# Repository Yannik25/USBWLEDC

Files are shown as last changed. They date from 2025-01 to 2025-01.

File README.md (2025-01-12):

# USBWLEDC
USB Sound Reactive WLED Controller



## Features

- USB-C for flashing and power (max. 3A)
- Small size (30mm x 35mm)
- Cheap components
- GSA4737 MEMS Microphone (similar to SPM1423)
- Solder Pads instead of Screw Terminal Blocks
- Files for panelized version (4x4)
- Files for 3D printed case
- Front side can be populated by JLCPCB

 

## Case



## Entering Flash Mode

To enter the Flash mode of the USBWLEDC, simply hold down the button as you connect the USB cable to a computer.

\* Update: With Rev. 1.2, CH340C has auto reset functionality, there should be no need to press the button during connection. 

## WLED Config

| Name | Value |
|---|---|
| LED Output 1: GPIO | 32 |
| LED Output 2: GPIO | 33 |
| Button 0: GPIO | 0 |
| Digitalmic: Type | Generic I2S PDM |
| Digitalmic: Pin I2S SD | GPIO 23 |
| Digitalmic: Pin I2S WS | GPIO 22 |

## BOM

|Designators |Footprint |Quantity|Value |LCSC Part #|
|---|---|---|---|---|
|C1*, C2, C4, C9, C10 |Capacitor_SMD:C_0402_1005Metric |5 |100nF |C1525  |
|C3, C5, C7 |Capacitor_SMD:C_0603_1608Metric |3 |10uF |C96446  |
|C6 |Capacitor_SMD:C_0402_1005Metric |1 |1uF |C52923  |
|C8 |Capacitor_SMD:CP_Elec_5x5.4 |1 |100uF |C7469983 |
|J10 |Connector_USB:USB_C_Receptacle_G-Switch_GT-USB-7010ASV |1 |USB-C Receptacle |C2988369|
|MK1* |Microphone:Microphone-6pin |1 |ICS-43434 MEMS Microphone|C5656610|
|R1* |Resistor_SMD:R_0402_1005Metric |1 |100k |C25741  |
|R2, R3, R6, R7 |Resistor_SMD:R_0402_1005Metric |4 |10k |C25531  |
|R4, R5 |Resistor_SMD:R_0603_1608Metric |2 |5.1k |C23186  |
|SW1 |Button_Switch_SMD:SW_Push_1P1T_XKB_TS-1187A |1 |Push Button Flash |C318884 |
|U2 |Package_TO_SOT_SMD:SOT-223-3_TabPin2 |1 |AMS1117-3.3 |C6186 |
|U3** |RF_Module:ESP32-WROOM-32E |1 |ESP32-WROOM-32E |C701341 |
|U4 		|Package_SO:VSSOP-8_2.3x2mm_P0.5mm			|1 		|SN74LVC2T45DCUR 		|C15741 |
|U5 		|Package_SO:SOIC-16_3.9x9.9mm_P1.27mm		|1 		|CH340C 				|C84681  |
|Q1, Q2 |Package_TO_SOT_SMD:SOT-23 |2 |L8050QLT1G |C49581 |
|D1 |Package_TO_SOT_SMD:SOT-143 |1 |SP0503BAHT |C2682275 |

\* You can build it without the microphone. Then you don't need R1, C1 and MK1.

\*\* The ESP32-WROOM Module can be purchased at a lower cost on AliExpress.

## Assembly

When ordering from JLCPCB, you have the option to get the front side of the board pre-populated - A service I strongly endorse. Subsequently, you'll only need to solder the ESP32-WROOM module onto the reverse side. With sufficient flux, this task can be accomplished with relative ease.

For those looking to populate the whole board, I suggest using a hot plate or a reflow oven for the front side.

    Be careful to keep Isopropyl Alcohol away from the hole of the microphone when cleaning the board!

## Disclaimer

The circuit board provided on this GitHub repository is offered "as is," without any warranties or guarantees of any kind. By accessing and utilizing this circuit board, you acknowledge and agree that you do so at your own risk.

The creator and contributor of this repository, shall not be held responsible or liable for any damages, losses, or injuries that may occur as a result of building and / or using this circuit board. This includes but is not limited to any direct, indirect, consequential, or incidental damages.

Electricity is dangerous. Only attempt this project if you know what you're doing.

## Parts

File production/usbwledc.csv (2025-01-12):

Comment | Designator | Footprint | LCSC
100nF | C1,C2,C4,C9,C10 | Capacitor_SMD:C_0402_1005Metric | C1525
10uF | C3,C5,C7 | Capacitor_SMD:C_0603_1608Metric | C96446
1uF | C6 | Capacitor_SMD:C_0402_1005Metric | C52923
100uF | C8 | Capacitor_SMD:CP_Elec_5x5.4 | C7469983
SP0503BAHT | D1 | Package_TO_SOT_SMD:SOT-143 | C2682275
5V PAD | J1,J4 | Library:SolderWirePad_1x01_SMD_3x6mm
USB_C_Receptacle_USB2.0 | J10 | Connector_USB:USB_C_Receptacle_G-Switch_GT-USB-7010ASV | C2988369
D1 PAD | J2 | Library:SolderWirePad_1x01_SMD_3x6mm
GND PAD | J3,J6 | Library:SolderWirePad_1x01_SMD_3x6mm
D2 PAD | J5 | Library:SolderWirePad_1x01_SMD_3x6mm
Accessories | J7 | Connector_PinHeader_2.54mm:PinHeader_1x06_P2.54mm_Vertical
Conn_01x03_Pin | J8,J9 | Connector_PinHeader_2.54mm:PinHeader_1x03_P2.54mm_Vertical
ICS-43434 | MK1 | microphone:Microphone-6pin | C5656610
L8050QLT1G | Q1,Q2 | Package_TO_SOT_SMD:SOT-23 | C49581
100k | R1 | Resistor_SMD:R_0402_1005Metric | C25741
10k | R2,R3,R6,R7 | Resistor_SMD:R_0402_1005Metric | C25531
5.1k | R4,R5 | Resistor_SMD:R_0603_1608Metric | C23186
FLASH_SW | SW1 | Button_Switch_SMD:SW_Push_1P1T_XKB_TS-1187A | C318884
AMS1117-3.3 | U2 | Package_TO_SOT_SMD:SOT-223-3_TabPin2 | C6186
ESP32-WROOM-32E-N4 | U3 | RF_Module:ESP32-WROOM-32E | C701341
SN74LVC2T45DCUR | U4 | Package_SO:VSSOP-8_2.3x2mm_P0.5mm | C15741
CH340C | U5 | Package_SO:SOIC-16_3.9x9.9mm_P1.27mm | C84681

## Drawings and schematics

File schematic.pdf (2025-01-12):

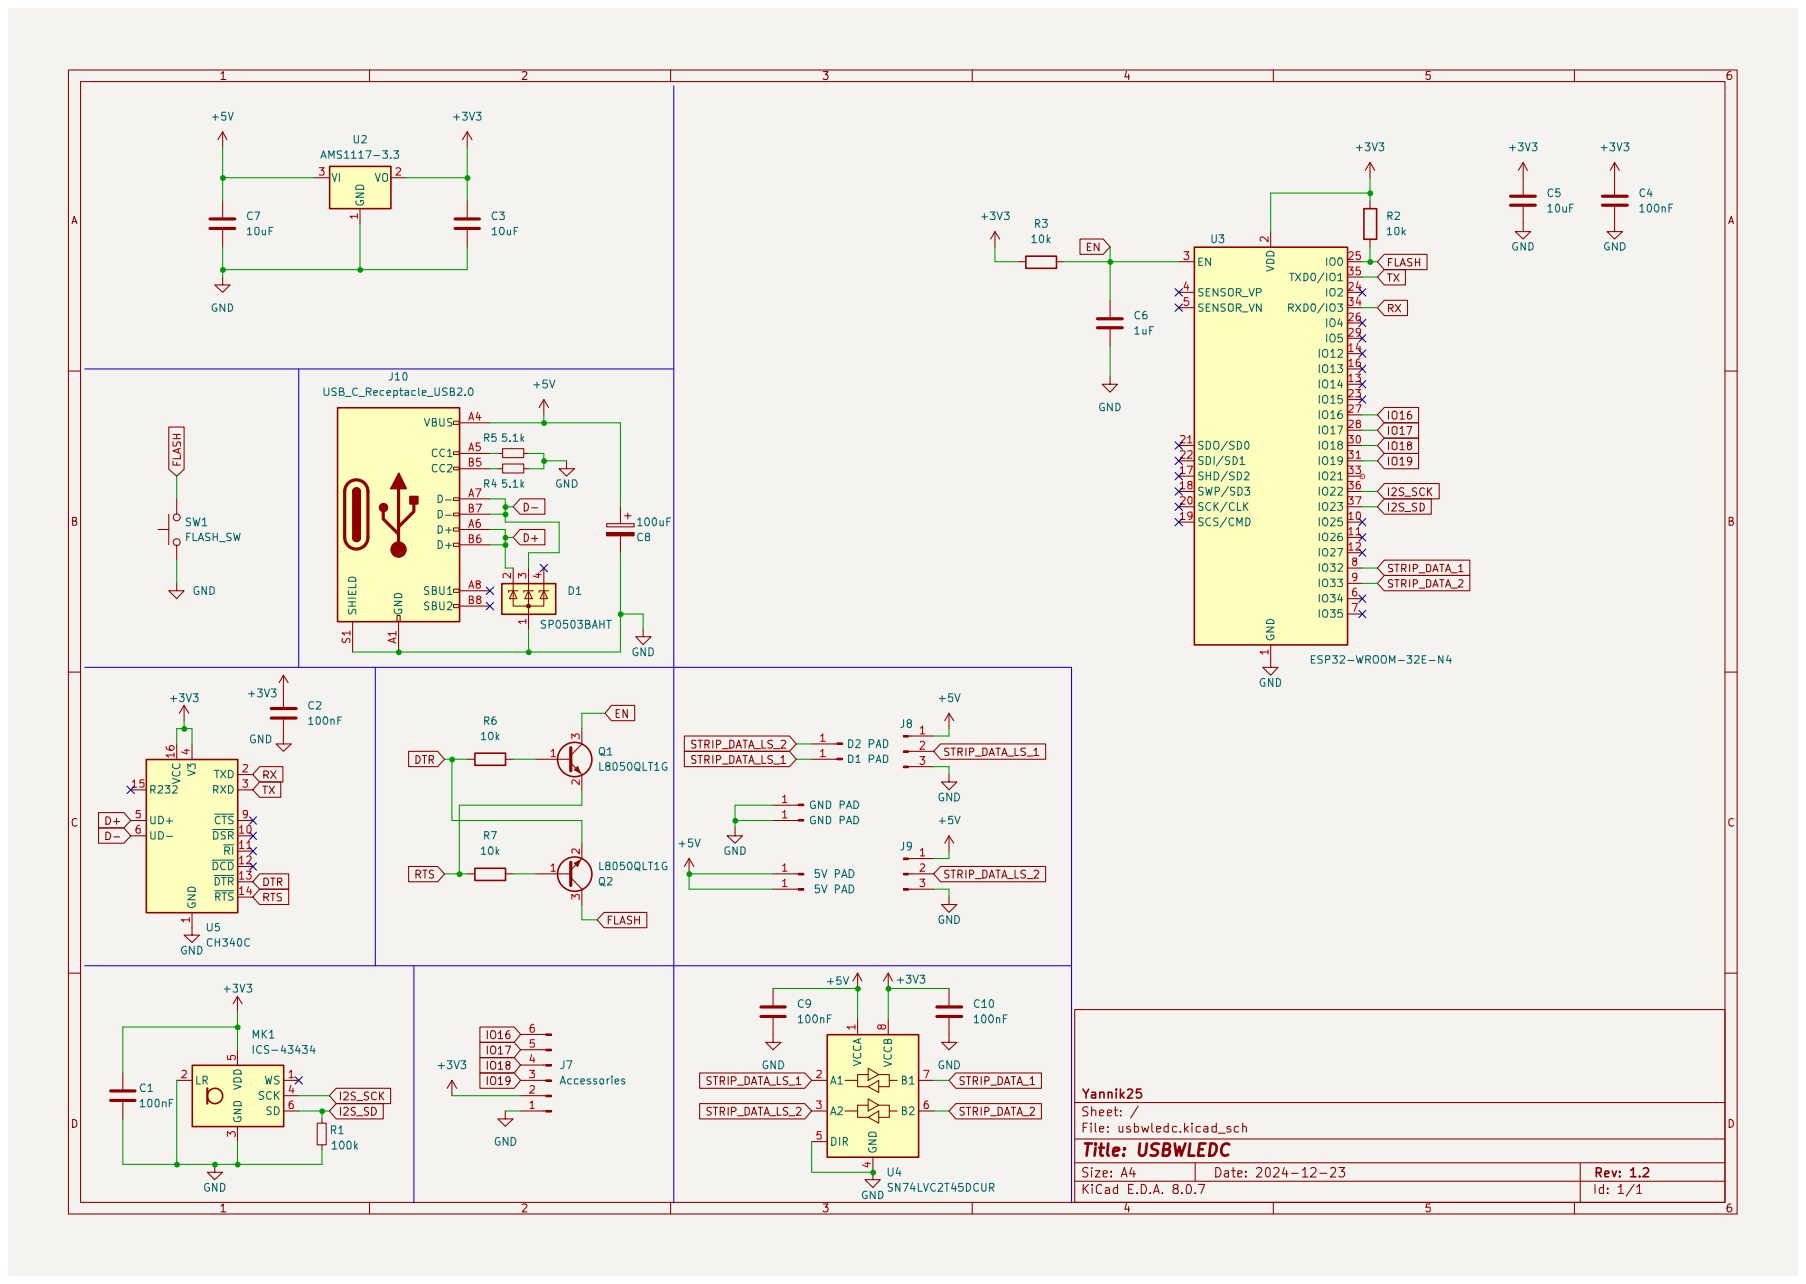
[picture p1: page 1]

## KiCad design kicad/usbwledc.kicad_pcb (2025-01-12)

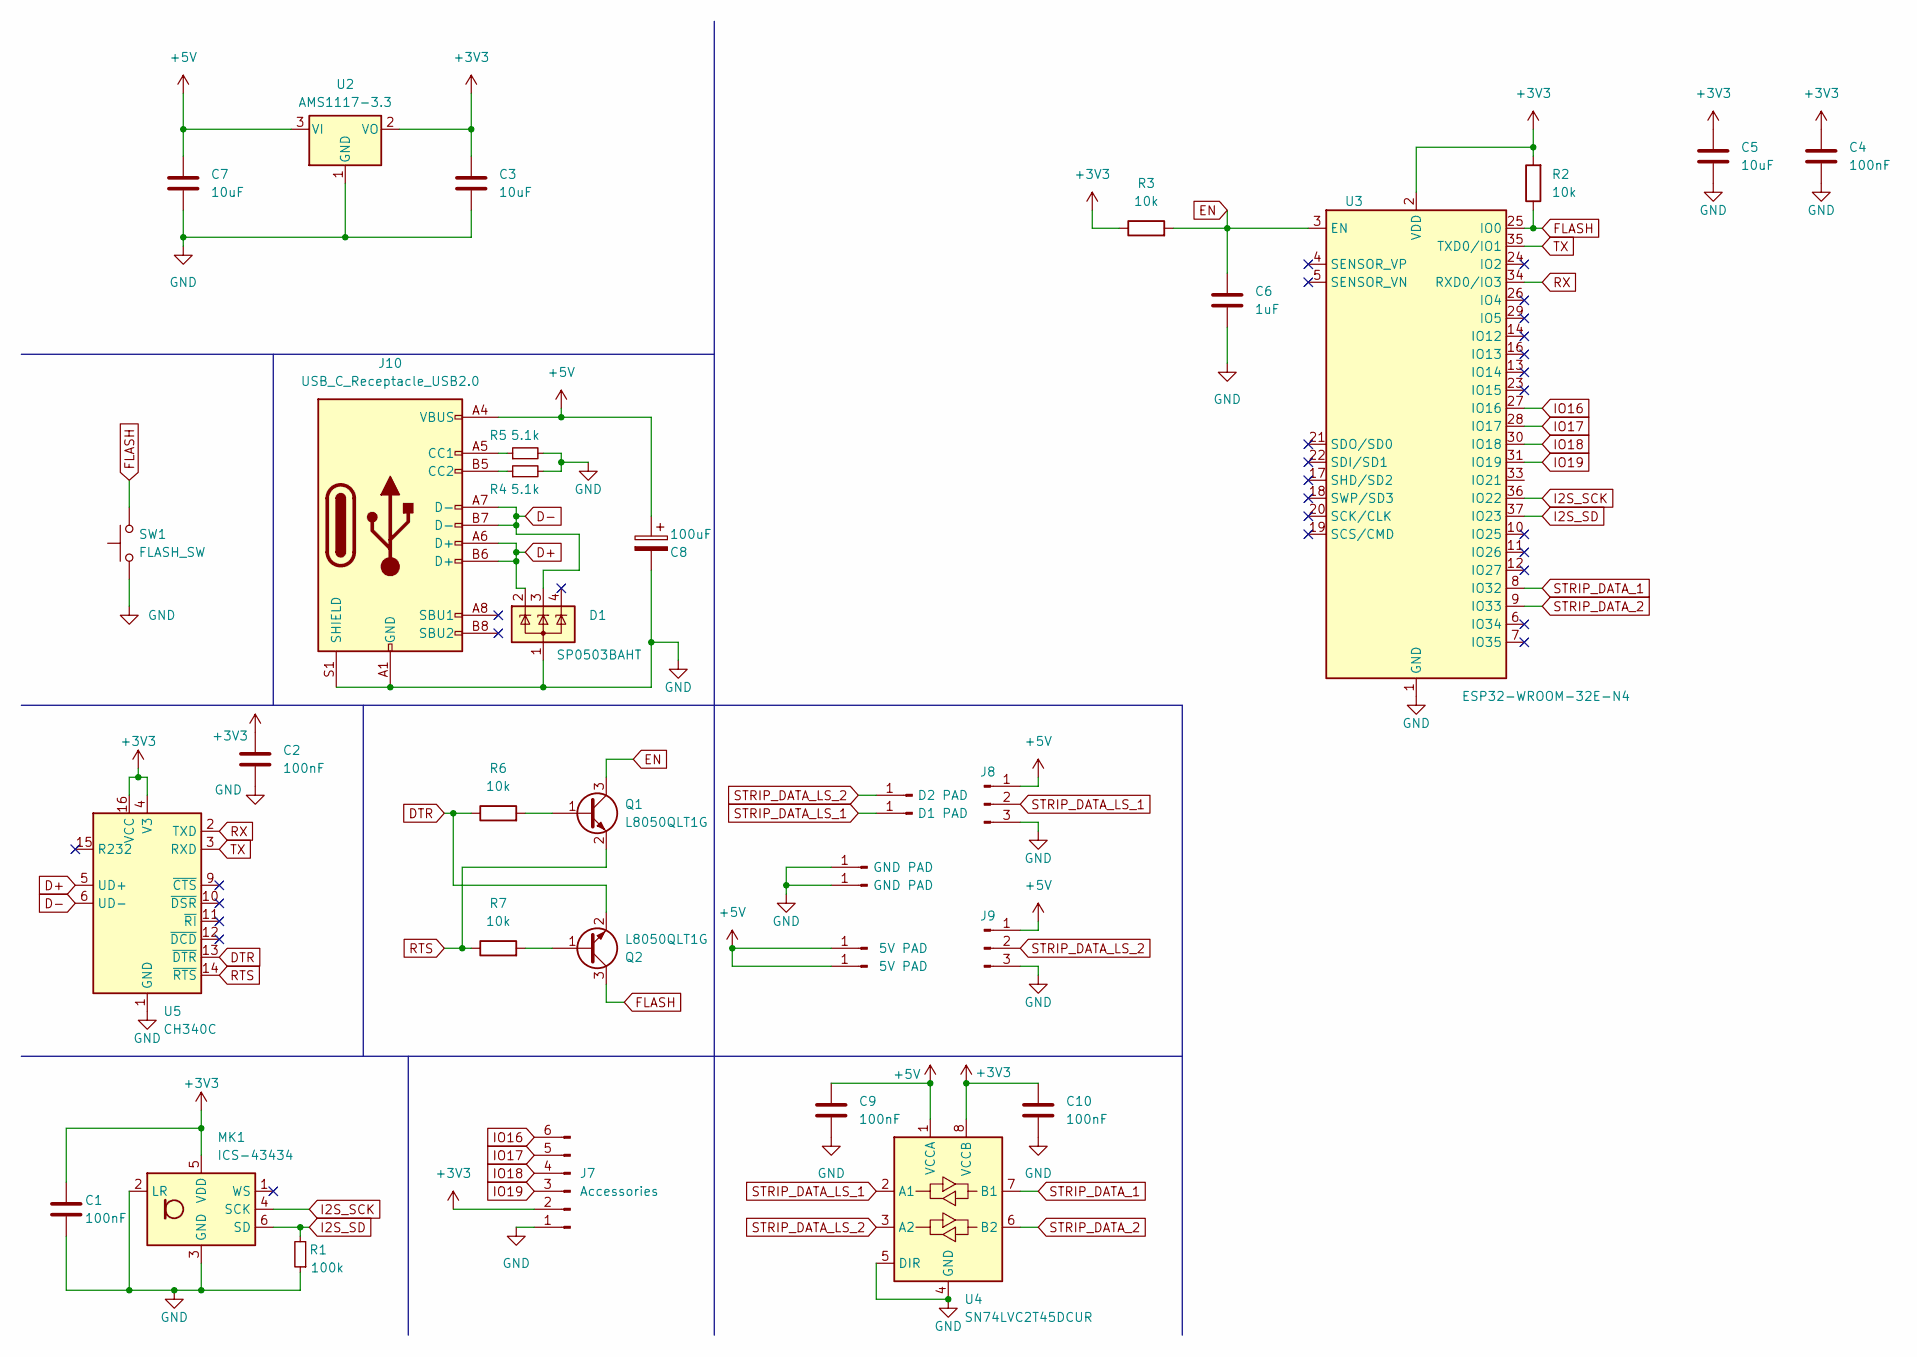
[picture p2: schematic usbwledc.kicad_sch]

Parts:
C1, C2, C4, C9, C10: 100nF; C_0402_1005Metric; MPN C1525; LCSC C1525
C3, C5, C7: 10uF; C_0603_1608Metric; MPN C96446; LCSC C96446
C6: 1uF; C_0402_1005Metric; MPN C52923; LCSC C52923
C8: 100uF; CP_Elec_5x5.4; MPN C7469983; LCSC C7469983
D1: SP0503BAHT; SOT-143; MPN C2682275; LCSC C2682275
J1, J4: 5V PAD; SolderWirePad_1x01_SMD_3x6mm
J2: D1 PAD; SolderWirePad_1x01_SMD_3x6mm
J3, J6: GND PAD; SolderWirePad_1x01_SMD_3x6mm
J5: D2 PAD; SolderWirePad_1x01_SMD_3x6mm
J7: Accessories; PinHeader_1x06_P2.54mm_Vertical
J8, J9: Conn_01x03_Pin; PinHeader_1x03_P2.54mm_Vertical
J10: USB_C_Receptacle_USB2.0; USB_C_Receptacle_G-Switch_GT-USB-7010ASV; MPN C2988369; LCSC C2988369
MK1: ICS-43434; InvenSense_ICS-43434-6_3.5x2.65mm; LCSC C5656610
Q1, Q2: L8050QLT1G; SOT-23; MPN C49581; LCSC C49581
R1: 100k; R_0402_1005Metric; MPN C25741; LCSC C25741
R2, R3, R6, R7: 10k; R_0402_1005Metric; MPN C25531; LCSC C25531
R4, R5: 5.1k; R_0603_1608Metric; MPN C23186; LCSC C23186
SW1: FLASH_SW; SW_Push_1P1T_XKB_TS-1187A; MPN C318884; LCSC C318884
U2: AMS1117-3.3; SOT-223-3_TabPin2; MPN C6186; LCSC C6186
U3: ESP32-WROOM-32E-N4; ESP32-WROOM-32E; MPN C701341; LCSC C701341
U4: SN74LVC2T45DCUR; VSSOP-8_2.3x2mm_P0.5mm; LCSC C15741
U5: CH340C; SOIC-16_3.9x9.9mm_P1.27mm; LCSC C84681

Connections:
+3V3: C1.1, C2.2, C3.1, C4.2, C5.1, C10.1, J7.2, MK1.5 (VDD), R2.2, R3.1, U2.2 (VO), U3.2 (VDD), U4.8 (VCCB), U5.4 (V3), U5.16 (VCC)
+5V: C7.1, C8.1, C9.1, J1.1, J4.1, J8.1, J9.1, J10.A4 (VBUS), J10.A9 (VBUS), J10.B4 (VBUS), J10.B9 (VBUS), U2.3 (VI), U4.1 (VCCA)
D+: D1.2 (K), J10.A6 (D+), J10.B6 (D+), U5.5 (UD+)
D-: D1.3 (K), J10.A7 (D-), J10.B7 (D-), U5.6 (UD-)
DTR: Q2.2 (E), R6.1, U5.13 (~DTR)
EN: C6.1, Q1.3 (C), R3.2, U3.3 (EN)
FLASH: Q2.3 (C), R2.1, SW1.2, U3.25 (IO0)
GND: C1.2, C2.1, C3.2, C4.1, C5.2, C6.2, C7.2, C8.2, C9.2, C10.2, D1.1 (A), J3.1, J6.1, J7.1, J8.3, J9.3, J10.A1 (GND), J10.A12 (GND), J10.B1 (GND), J10.B12 (GND), J10.S1 (SHIELD), MK1.2 (LR), MK1.3 (GND), R1.1, R4.2, R5.2, SW1.1, U2.1 (GND), U3.1 (GND), U3.15 (GND), U3.38 (GND), U3.39 (GND), U4.4 (GND), U4.5 (DIR), U5.1 (GND)
I2S_SCK: MK1.4 (SCK), U3.36 (IO22)
I2S_SD: MK1.6 (SD), R1.2, U3.37 (IO23)
IO16: J7.6, U3.27 (IO16)
IO17: J7.5, U3.28 (IO17)
IO18: J7.4, U3.30 (IO18)
IO19: J7.3, U3.31 (IO19)
unnamed: J10.A5 (CC1), R5.1
unnamed: J10.B5 (CC2), R4.1
unnamed: Q1.1 (B), R6.2
unnamed: Q2.1 (B), R7.2
RTS: Q1.2 (E), R7.1, U5.14 (~RTS)
RX: U3.34 (RXD0/IO3), U5.2 (TXD)
STRIP_DATA_1: U3.8 (IO32), U4.7 (B1)
STRIP_DATA_2: U3.9 (IO33), U4.6 (B2)
STRIP_DATA_LS_1: J2.1, J8.2, U4.2 (A1)
STRIP_DATA_LS_2: J5.1, J9.2, U4.3 (A2)
TX: U3.35 (TXD0/IO1), U5.3 (RXD)

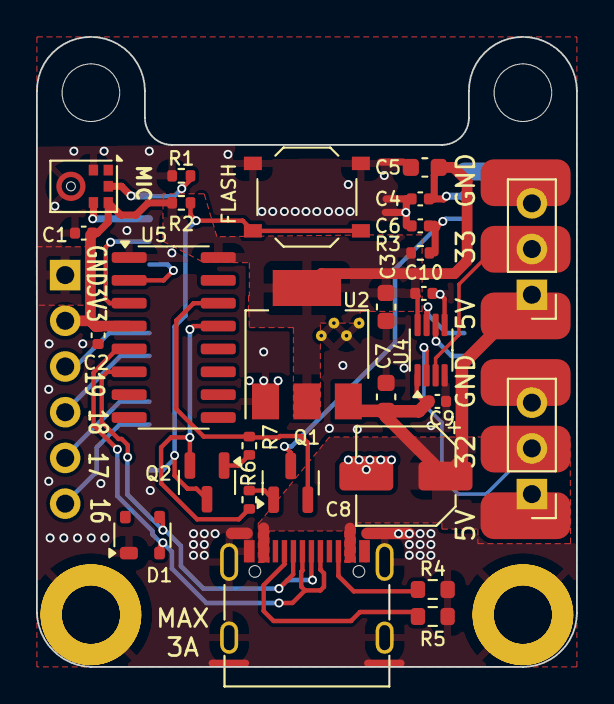
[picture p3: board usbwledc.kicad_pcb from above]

Board: 2 copper layers, 30.0 x 35.0 mm, 40 parts (1 on the bottom side), 25 nets.

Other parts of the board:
H1, H2, H3, H4: MountingHole; MountingHole_3.2mm_M3_DIN965_Pad

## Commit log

2024-12-23 update to Revision 1.2
    Updated:
    ESP32-WROOM-32 to ESP32-WROOM-32E
    Changed CH340N to CH340C with Auto reset function
    Changed components from 0805 to 0603/0402
    Updated JLCPC component C8 to C7469983
    Added:
    SN74LVC2T45DCUR Levelshifter from 3.3V to 5V
    USB Data ESD protection
    [bom.csv, panel.kicad_pcb, usbwledc.csv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]
2025-01-12 fix resistor placement instead of caps, replace mic, fix count of components
    [usbwledc.csv, usbwledc.kicad_pcb, usbwledc.kicad_sch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]
